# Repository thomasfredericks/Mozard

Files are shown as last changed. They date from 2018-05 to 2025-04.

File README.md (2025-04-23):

# Mozard

Mozard is a miniature, open-source digital synthesizer based on the Mozzi audio library and an Arduino Nano (ATmega328p) board.

[Video demonstration](https://youtu.be/wlpf26ogcaQ)

Features :

- 12 capacitive touch pads (one full octave)
- 6 different sound algorithms
- MIDI input support
- Octave control via potentiometer
- Volume control via potentiometer
- Built-in arpeggiator
- Decay and arpeggiator speed control

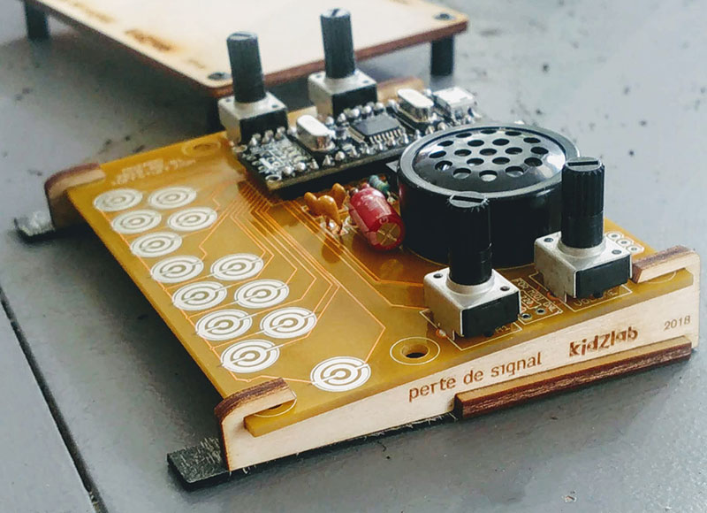
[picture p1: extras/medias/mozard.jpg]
A picture of the Mozard Mozard Kidzlab Synth


## Usage

The Mozard changes behavior when the arpeggiator is deactivated or activated. When in arpeggiator mode, the LED on the Arduino blinks in sync with the arpeggiator interval.

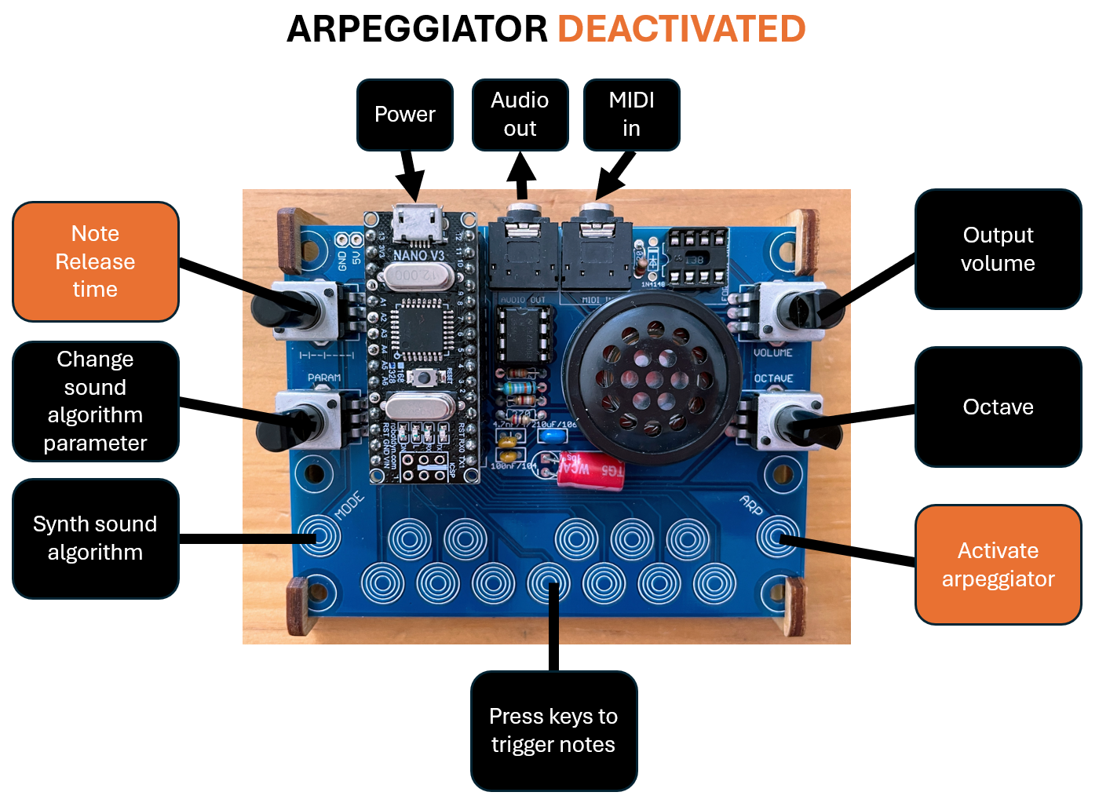
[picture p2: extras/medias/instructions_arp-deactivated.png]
How to use the Mozard when the arpeggiator is deactivated


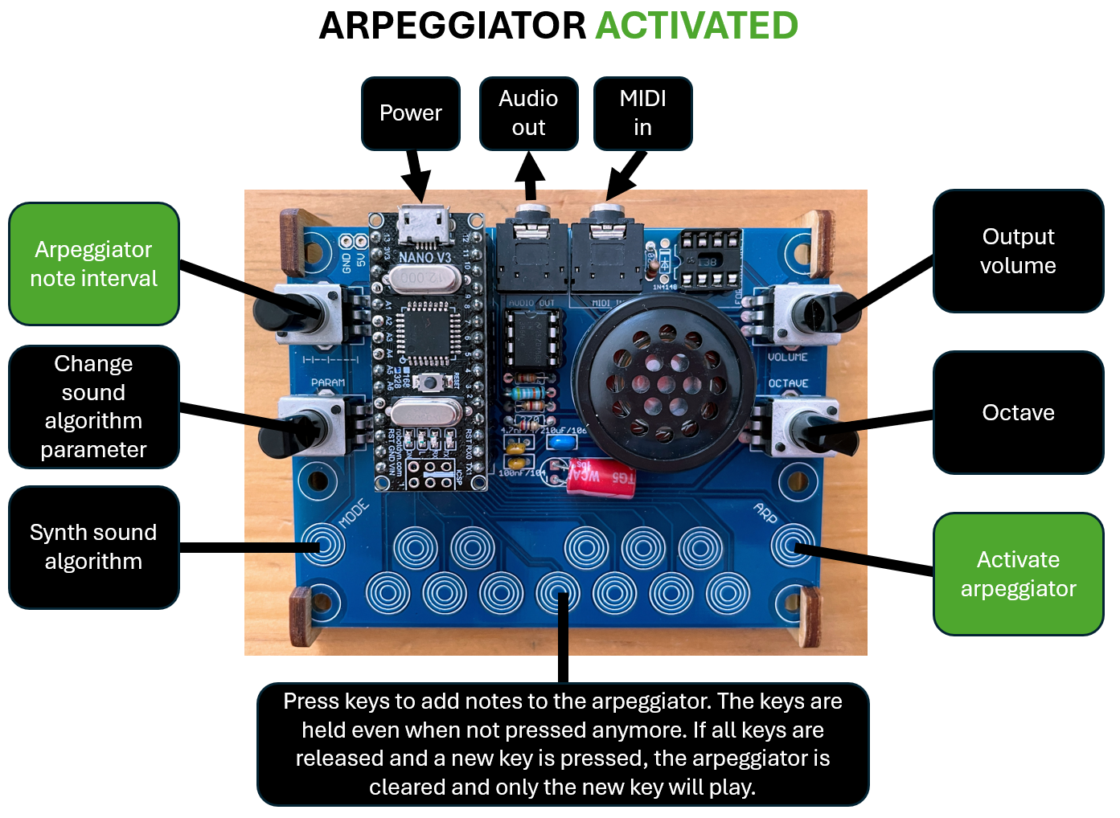
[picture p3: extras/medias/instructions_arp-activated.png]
How to use the Mozard when the arpeggiator is activated


## Hardware

The circuit and Bill Of Materials can be found in the extras/circuit folder.

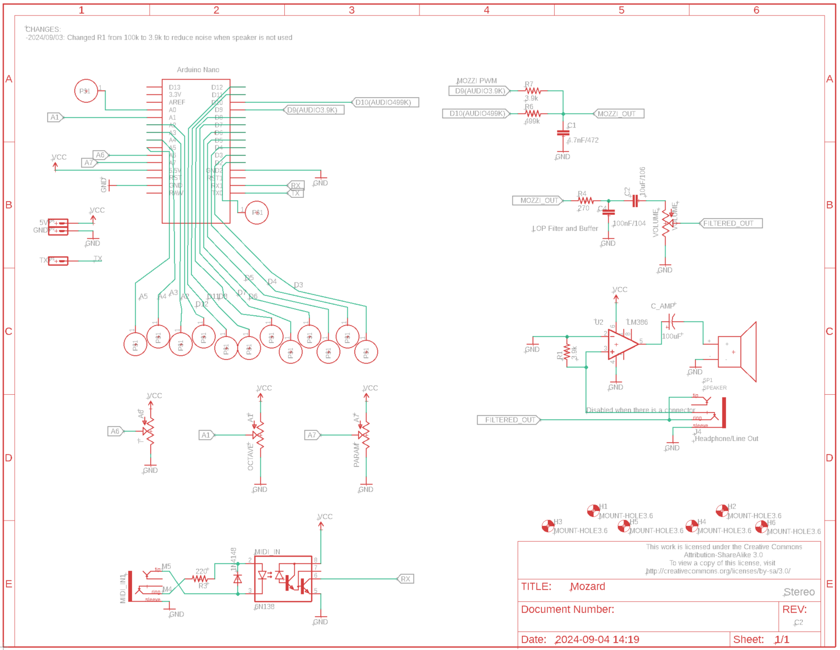
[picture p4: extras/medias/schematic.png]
A picture of Mozard schematic


## Source code

1) Download the library source code [here](https://github.com/thomasfredericks/Mozard/archive/refs/heads/master.zip).

2) Extract into your Arduino libraries folder. It should look something like this:
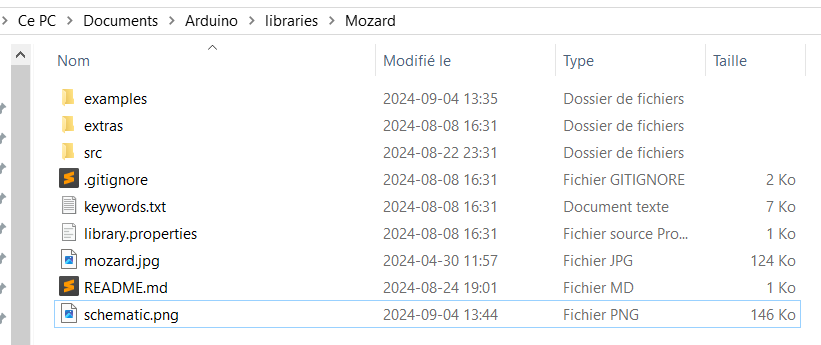
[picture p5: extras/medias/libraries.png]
The installed Mozard library in the Arduino libraries folder


3) Open Arduino.

4) Find the latest example:
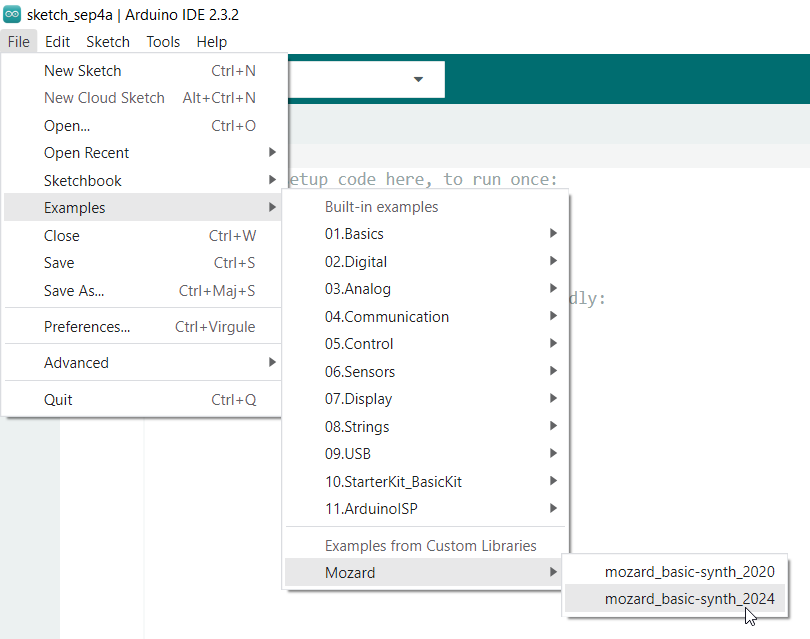
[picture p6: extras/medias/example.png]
Finding the latest example


5) Configure Arduino for the right microcontroller i.e. "Arduino Nano":
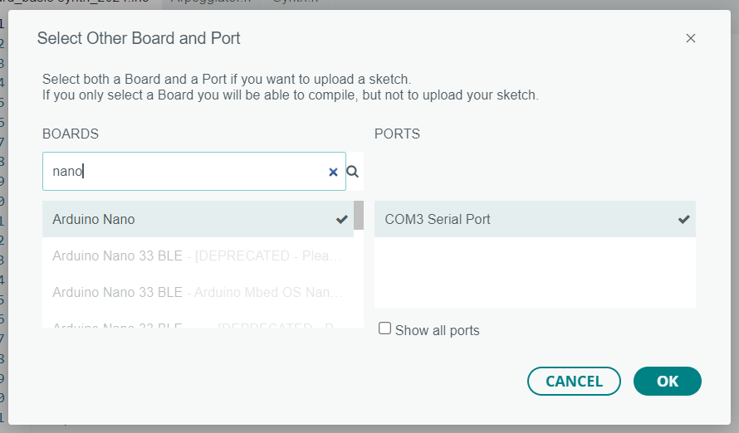
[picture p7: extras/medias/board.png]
Selecting Arduino Nano Board


7) Configure Arduino for the right Bootloader i.e. "ATmega328 (Old Bootloader)"  if you followed a Mozard workshop or bought a clone:
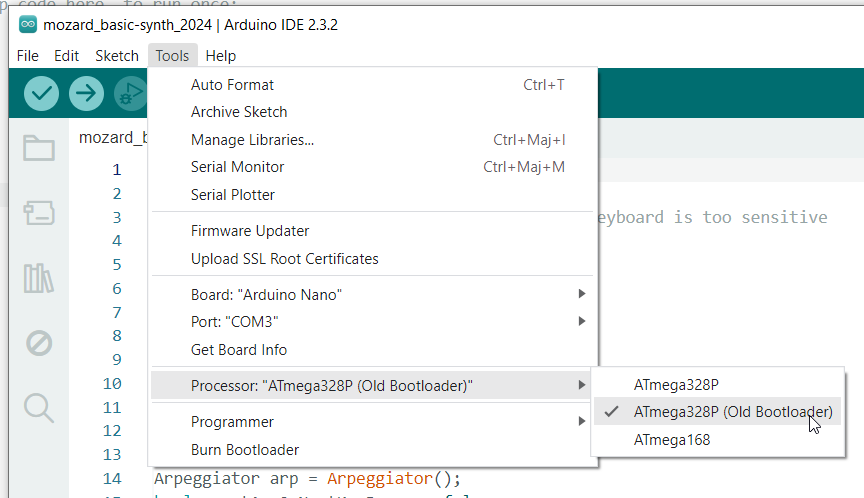
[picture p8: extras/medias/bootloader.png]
Selecting ATmega328 (Old Bootloader)


8) Compile and transfer.

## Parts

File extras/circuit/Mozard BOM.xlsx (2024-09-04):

Module | Quantity | Part | Digikey | Aliexpress
CORE | 1 | PCB
CORE | 1 | 4.7nF/472 CAPACITOR | ‎K472K15X7RF5TL2‎
CORE | 1 | 10uF/106 CAPACITOR | FK16X7R1C106K‎ or FK16X7R1C106M
CORE | 1 | 100nF/104 CAPACITOR | ‎K104K10X7RF53L2‎
CORE | 4 | ALPS POTENTIOMETER | ‎PTV09A-4020F-B503‎ | https://tinyurl.com/yywexyto (50k model) (https://tinyurl.com/yywexyto%20(50k%20model))
CORE | 1 | 270 RESISTOR | CFM14JT270R
CORE | 1 | 499k RESISTOR | RNF14FTD499K‎
CORE | 1 | 3.9k RESISTOR | CFM14JT3K90‎
CORE | 1 | AUDIO-JACK | SJ1-3525N | http://tinyurl.com/y95h5cap
CORE | 2 | FEMALE HEADERS | PPTC151LFBN-RC | https://tinyurl.com/y6tcve45
CORE | 1 | ARDUINO NANO 328 |  | https://tinyurl.com/y2zfy82b
SPEAKER | 1 | 3.9k RESISTOR | CFM14JT3K90‎
SPEAKER | 1 | LM386 | LM386N-4/NOPB‎ | http://tinyurl.com/yd4p9tap
SPEAKER | 1 | SPEAKER | 668-1136-ND | https://tinyurl.com/yxnvhumu
MIDI IN | 1 | AUDIO-JACK | CP1-3525N-ND | http://tinyurl.com/y95h5cap
MIDI IN | 1 | 6N138 | 160-1795-ND (https://www.digikey.ca/product-detail/en/lite-on-inc/6N138/160-1795-ND/1969179) | https://tinyurl.com/y5rocrjj
MIDI IN | 1 | 1N4148 | 1N4148FS-ND (https://www.digikey.ca/product-detail/en/on-semiconductor/1N4148/1N4148FS-ND/458603) | https://tinyurl.com/y25v8b57
MIDI IN | 1 | 220 RESISTOR | CFM14JT220R (https://www.digikey.ca/product-detail/en/stackpole-electronics-inc/CFM14JT220R/S220QCT-ND/2617711)

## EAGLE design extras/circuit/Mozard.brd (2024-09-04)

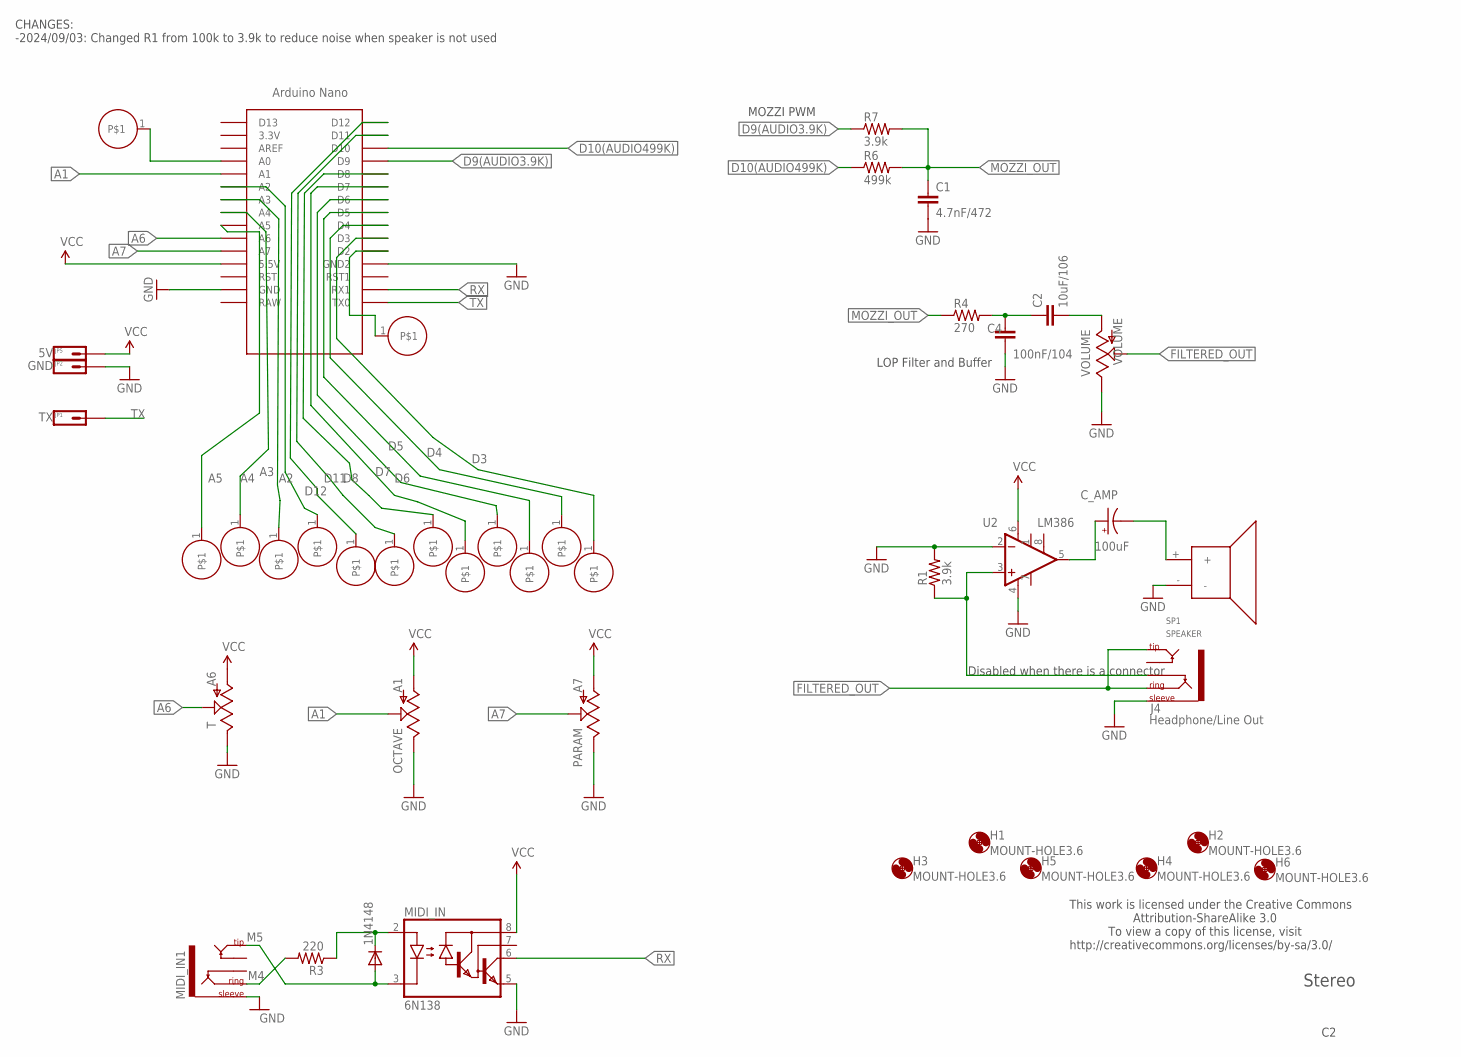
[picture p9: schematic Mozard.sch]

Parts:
1N4148: 1N4148; DO41-10
C1: 4.7nF/472; CAP-PTH-SMALL-KIT
C2: 10uF/106; CAP-PTH-SMALL-KIT
C4: 100nF/104; CAP-PTH-SMALL-KIT
C_AMP: 100uF; CPOL-RADIAL-10UF-25V
H1, H2, H3, H4, H5, H6: MOUNT-HOLE3.6; 3,6
J4: Headphone/Line Out; AUDIO-JACK
JP1: TX; 1X01_SIDE_NAME
JP2: GND; 1X01_SIDE_NAME
JP5: 5V; 1X01_SIDE_NAME
MIDI_IN: 6N138; DIL08
MIDI_IN1: AUDIO-JACKKIT; AUDIO-JACK-KIT
OCTAVE: A1; ALPS_POT
PARAM: A7; ALPS_POT
R1, R7: 3.9k; 0204/7
R3: 220; 0204/5
R4: 270; 0204/7
R6: 499k; 0204/7
SP1: SPEAKER; PCB_MOUNT_SPEAKER
T: A6; ALPS_POT
U2: LM386; DIP08
U$1: NANO
U$2, U$3, U$4, U$5, U$6, U$7, U$8, U$9, U$10, U$11, U$12, U$13, U$14, U$15: PCB-TOUCHPAD-1-PIN
VOLUME: VOLUME; ALPS_POT

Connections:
A1: OCTAVE.P$2 (S), U$1.A1
A2: U$1.A2, U$5.1
A3: U$1.A3, U$4.1
A4: U$1.A4, U$3.1
A5: U$1.A5, U$2.1
A6: T.P$2 (S), U$1.A6
A7: PARAM.P$2 (S), U$1.A7
D3: U$1.D3, U$13.1
D4: U$1.D4, U$12.1
D5: U$1.D5, U$11.1
D6: U$1.D6, U$10.1
D7: U$1.D7, U$9.1
D8: U$1.D8, U$8.1
D9(AUDIO3.9K): R7.1, U$1.D9
D10(AUDIO499K): R6.1, U$1.D10
D11: U$1.D11, U$7.1
D12: U$1.D12, U$6.1
FILTERED_OUT: J4.RING, J4.TIP, VOLUME.P$2 (S)
GND: C1.2, C4.2, J4.SLEEVE, JP2.1, MIDI_IN.5 (GND), MIDI_IN1.SLEEVE, OCTAVE.P$1 (E), PARAM.P$1 (E), R1.2, SP1.-, T.P$1 (E), U2.2 (-IN), U2.4 (V-), U$1.GND, U$1.GND1 (GND2), VOLUME.P$1 (E)
M4: MIDI_IN1.RING, R3.2
M5: 1N4148.A, MIDI_IN.3 (C), MIDI_IN1.TIP
MOZZI_OUT: C1.1, R4.1, R6.2, R7.2
unnamed: C_AMP.+, U2.5 (OUT)
unnamed: C2.2, VOLUME.P$3 (A)
unnamed: U$1.A0, U$15.1
unnamed: C2.1, C4.1, R4.2
unnamed: C_AMP.-, SP1.+
unnamed: J4.RSH, R1.1, U2.3 (+IN)
unnamed: 1N4148.C, MIDI_IN.2 (A), R3.1
RX: MIDI_IN.6 (VO), U$1.RX1
TOUCH_A: U$1.D2, U$14.1
TX: JP1.1, U$1.TX0
VCC: JP5.1, MIDI_IN.8 (VCC), OCTAVE.P$3 (A), PARAM.P$3 (A), T.P$3 (A), U2.6 (V+), U$1.5V (5.5V)

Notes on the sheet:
Stereo
Disabled when there is a connector
This work is licensed under the Creative Commons Attribution-ShareAlike 3.0 To view a copy of this license, visit http://creativecommons.org/licenses/by-sa/3.0/
LOP Filter and Buffer
MOZZI PWM
CHANGES: -2024/09/03: Changed R1 from 100k to 3.9k to reduce noise when speaker is not used

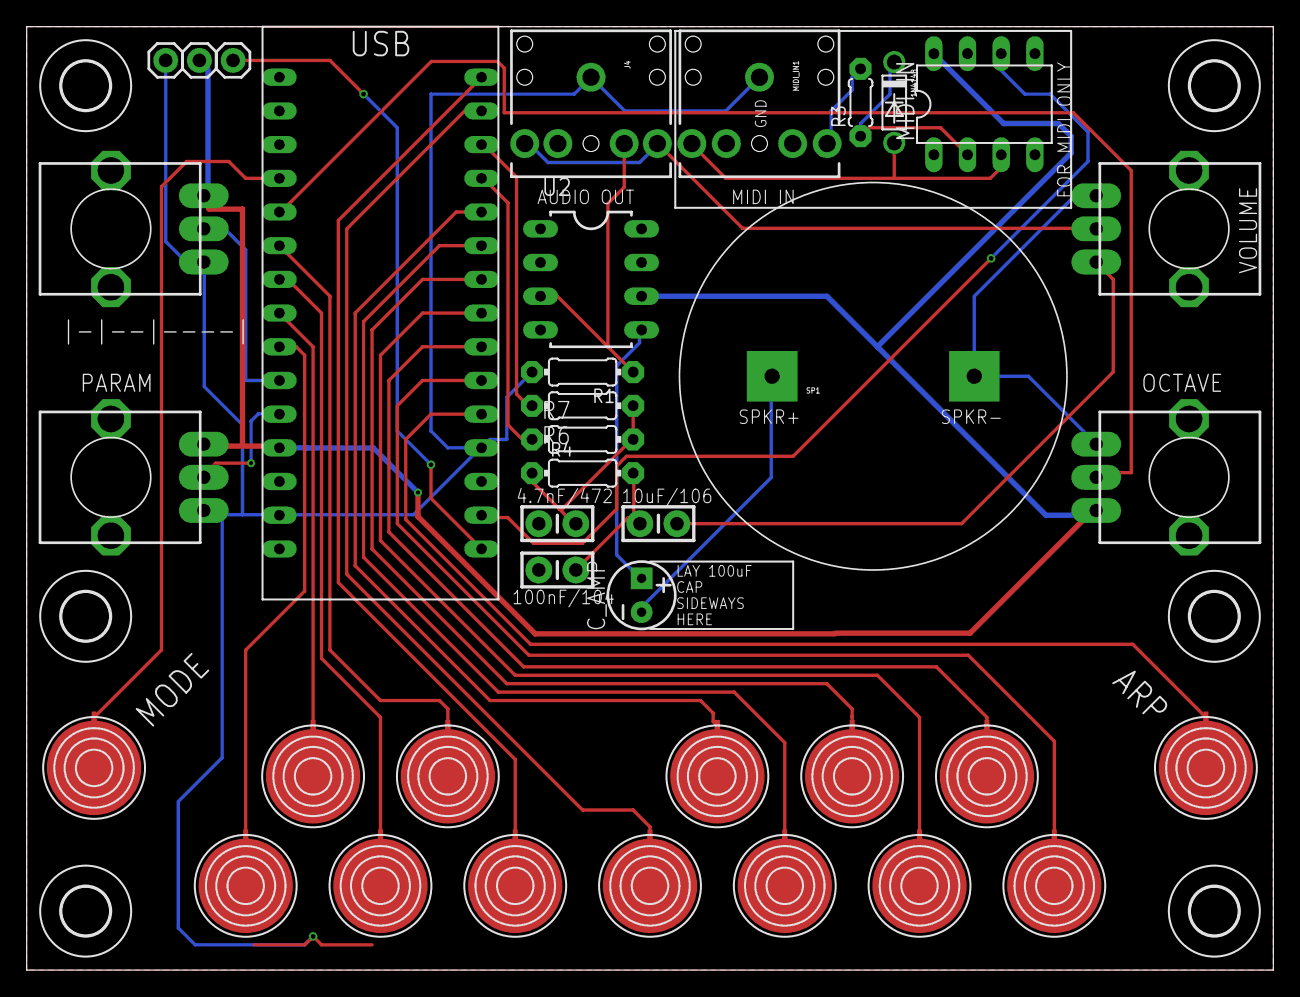
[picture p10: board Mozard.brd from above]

Board: 2 copper layers, 94.0 x 71.1 mm, 43 parts (0 on the bottom side), 33 nets.

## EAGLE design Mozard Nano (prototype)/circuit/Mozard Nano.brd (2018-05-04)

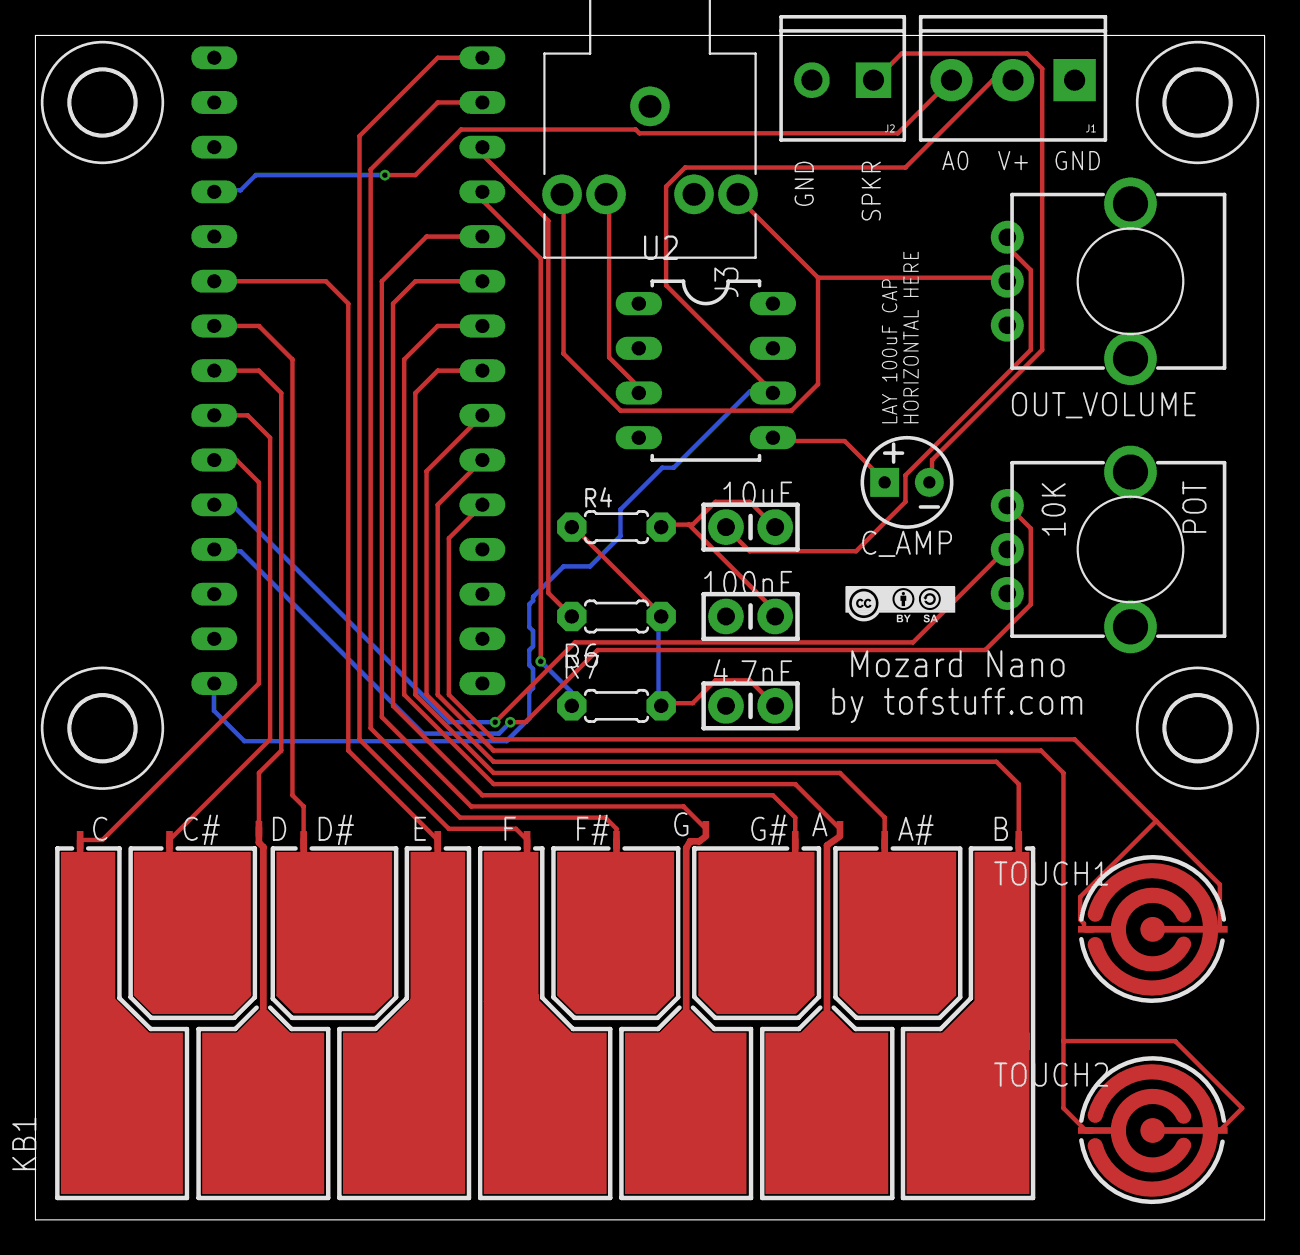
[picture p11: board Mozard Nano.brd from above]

Board: 2 copper layers, 69.8 x 67.3 mm, 22 parts (0 on the bottom side), 28 nets.

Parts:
C1: 4.7nF; CAP-PTH-SMALL-KIT
C2: 10uF; CAP-PTH-SMALL-KIT
C4: 100nF; CAP-PTH-SMALL-KIT
C_AMP: 100uF; CPOL-RADIAL-10UF-25V
H1, H2, H3, H4: MOUNT-HOLE3.6; 3,6
J1: SCREWTERMINAL-3.5MM-3
J2: SPKR; SCREWTERMINAL-3.5MM-2
J3: OUT; STEREO-AUDIO-3.5MM-SWITCHED
KB1: PCB-KEYBOARD4
OUT_VOLUME: 10K; ALPS_POT_KIT
POT: 10K; ALPS_POT_KIT
R4: 270; 0204/5
R6: 499k; 0204/5
R7: 3.9k; 0204/5
TOUCH1, TOUCH2: PCB-TOUCHPAD2
U2: LM386; DIP08
U$1: NANO
U$2: CC-BY-SA-LOGO2

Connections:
A0: J1.3, U$1.A0
D2(C): KB1.D#, U$1.A3
D9(AUDIO3.9K): R7.1, U$1.D9
D10(AUDIO499K): R6.1, U$1.D10
GND: C1.2, C4.2, J1.1, J2.2, J3.1, OUT_VOLUME.P$3, POT.P$3, U2.2, U2.4, U$1.GND, U$1.GND1
unnamed: C_AMP.-, J2.1
unnamed: KB1.E, U$1.A2
unnamed: KB1.C, U$1.A6
unnamed: C2.1, C4.1, R4.2
unnamed: C2.2, OUT_VOLUME.P$1
unnamed: J3.4, U2.3
unnamed: C_AMP.+, U2.5
unnamed: J3.2, J3.5, OUT_VOLUME.P$2
unnamed: KB1.C#, U$1.A5
unnamed: KB1.D, U$1.A4
unnamed: KB1.F, U$1.D12
unnamed: KB1.F#, U$1.D11
unnamed: KB1.G, U$1.D8
unnamed: KB1.G#, U$1.D7
unnamed: KB1.A, U$1.D6
unnamed: KB1.A#, U$1.D5
unnamed: KB1.B, U$1.D4
POT: POT.P$2, U$1.A7
TOUCH_A: TOUCH1.1, TOUCH1.2, U$1.D2
TOUCH_B: TOUCH2.1, TOUCH2.2, U$1.D3
UNFILTERED_OUT: C1.1, R4.1, R6.2, R7.2
V+: J1.2, U2.6, U$1.RAW
VCC: POT.P$1, U$1.5V

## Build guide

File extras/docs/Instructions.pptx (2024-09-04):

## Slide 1

ARPEGGIATOR DEACTIVATED

Power

Audio out

MIDI
in

Note Release time

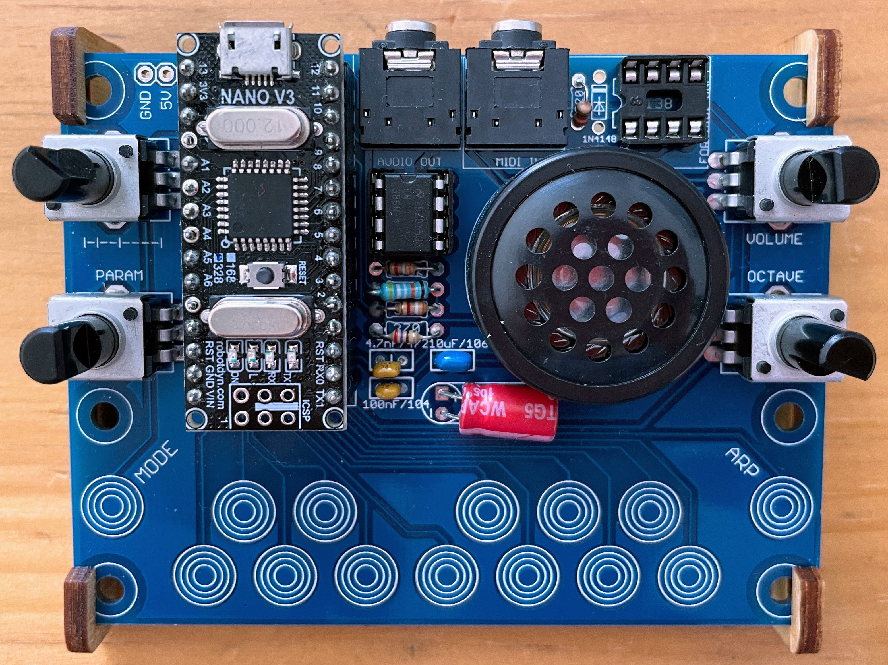
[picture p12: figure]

Output volume

Change sound algorithm parameter

Octave

Synth sound algorithm

Activate arpeggiator

Press keys to trigger notes

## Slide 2

ARPEGGIATOR ACTIVATED

Power

Audio out

MIDI
in

Arpeggiator note interval

Press keys to add notes to the arpeggiator. The keys are held even when not pressed anymore. If all keys are released and a new key is pressed, the arpeggiator is cleared and only the new key will play.

Output volume

Change sound algorithm parameter

Octave

Synth sound algorithm

Activate arpeggiator

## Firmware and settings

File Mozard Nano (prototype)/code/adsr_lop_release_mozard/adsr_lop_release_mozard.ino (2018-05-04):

/*
    IMPORTANT: this sketch requires Mozzi/mozzi_config.h to be
    be changed from STANDARD mode to HIFI.
    In Mozz/mozzi_config.h, change
    #define AUDIO_MODE STANDARD
    //#define AUDIO_MODE HIFI
    to
    //#define AUDIO_MODE STANDARD
    #define AUDIO_MODE HIFI

*/


#include <MozziGuts.h>
#include <Oscil.h>
#include <Ead.h> // Exponential attack decay envelope.
#include <mozzi_rand.h>
#include <mozzi_midi.h>
#include <LowPassFilter.h>
#include <ADSR.h>

// powers of 2 please : fast control rate for fast key response
#define CONTROL_RATE 256

//Oscillator Tables used for output Waveshape
// SELECT ONE PAIR :
//#include <tables/sin2048_int8.h>
//Oscil <2048, AUDIO_RATE> osc(SIN2048_DATA);

//#include <tables/triangle2048_int8.h>
//Oscil <2048, AUDIO_RATE> osc(TRIANGLE2048_DATA);

//#include <tables/saw2048_int8.h>
//Oscil <2048, AUDIO_RATE> osc(SAW2048_DATA);

#include <tables/square_no_alias_2048_int8.h>
Oscil <2048, AUDIO_RATE> osc(SQUARE_NO_ALIAS_2048_DATA);

// LFO TABLE
#include <tables/cos2048_int8.h> // for filter modulation
Oscil<COS2048_NUM_CELLS, CONTROL_RATE> lfo(COS2048_DATA);


ADSR <CONTROL_RATE, AUDIO_RATE> envelope;

LowPassFilter lpf;

uint8_t lastNote;

#include "MozardNano.h"

void setup() {

  Serial.begin(57600);
  startMozzi(CONTROL_RATE);


  // HARDWARE SETUP
  mozard.setup();

  lpf.setResonance(10);

  envelope.setADLevels(250,250);               // Sets Attack and Decay Levels; assumes Sustain, Decay, and Idle times
  envelope.setDecayTime(100);                  // Sets Decay time in milliseconds
  envelope.setSustainTime(32500);              // Sustain Time setting for envelope
  envelope.setReleaseTime(250); 

}


void updateControl() {

  mozard.updateControl();

  if ( mozard.buttonUpPressed() ) mozard.octaveUp();
  if ( mozard.buttonDownPressed() ) mozard.octaveDown();

  if ( mozard.keyPressed() ) {
    lastNote = mozard.getNotePressed();
    int freq = mtof(lastNote);
    
    osc.setFreq(freq);

    envelope.noteOn();

  }

  if ( mozard.keyReleased() ) {
    if ( lastNote == mozard.getNoteReleased() ) envelope.noteOff();
     
  }

 
  envelope.update();
  
   int pot = mozard.getPot0();
  
   lfo.setFreq( (float)pot * 0.05f);
   byte cutoff_freq = lfo.next() / 4 + 32;
   lpf.setCutoffFreq(cutoff_freq);


}


int updateAudio() {

 return (int) (lpf.next(osc.next()) * envelope.next())>>2;
}


void loop() {
  audioHook();
}

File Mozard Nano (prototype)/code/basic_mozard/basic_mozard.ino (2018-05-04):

/*
    IMPORTANT: this sketch requires Mozzi/mozzi_config.h to be
    be changed from STANDARD mode to HIFI.
    In Mozz/mozzi_config.h, change
    #define AUDIO_MODE STANDARD
    //#define AUDIO_MODE HIFI
    to
    //#define AUDIO_MODE STANDARD
    #define AUDIO_MODE HIFI

*/


#include <MozziGuts.h>
#include <Oscil.h>
#include <Ead.h> // Exponential attack decay envelope.
#include <mozzi_rand.h>
#include <mozzi_midi.h>
#include <tables/sin2048_int8.h> // sine table for oscillator

#include "MozardNano.h"

// powers of 2 please
#define CONTROL_RATE 256

Oscil <SIN2048_NUM_CELLS, AUDIO_RATE> aSin(SIN2048_DATA);
Ead envelope(CONTROL_RATE);
int gain;

unsigned int attack_ms = 10;
unsigned int decay_ms = 200;

void setup() {

  Serial.begin(57600);
  startMozzi(CONTROL_RATE);

  mozard.setup();

}


void updateControl() {

  mozard.updateControl();

  if ( mozard.buttonUpPressed() ) mozard.octaveUp();
  if ( mozard.buttonDownPressed() ) mozard.octaveDown(); 

  if ( mozard.keyPressed() ) {
    uint8_t note = mozard.getNotePressed();
    int freq = mtof(note);
    aSin.setFreq(freq);

    int pot = mozard.getPot0();
    envelope.start(attack_ms, pot * 2 + decay_ms);
    
  }

  gain = (int) envelope.next();

}


int updateAudio() {
  //return aSin.next() << 6; // 8 bits scaled up to 14 bits

  return (int) (gain * aSin.next()) >> 2; // 16 bits scaled to 14 bits
}


void loop() {
  audioHook();
}

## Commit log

2018-05-20 Fixes and added other potentiometer
    [Mozard Nano.brd, Mozard Nano.sch]
2018-05-22 Separating prototype from final version
    [Mozard Nano.GBL, Mozard Nano.GBO, Mozard Nano.GBP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]
2018-07-25 Mozard Nano Prototype Release
    [Mozard Nano.brd, Mozard Nano.sch, Mozard.brd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]
2018-07-25 Version 1.00
    [Mozard Nano.brd, Mozard Nano.sch, Mozard.brd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]
2018-07-25 New version with grounded touch pads
    [Mozard Grounded Touch Pads.brd, Mozard Grounded Touch Pads.sch]
2018-07-27 Adding examples
    [Mozard Grounded Touch Pads.brd, Mozard Grounded Touch Pads.sch]
2018-07-27 Version sub directory
    [Mozard.brd, Mozard.sch]
2018-09-12 integrated Mozzi
    [Mozard.brd, Mozard.sch]
2018-09-12 Added circuit
    [Mozard.brd, Mozard.sch]
2019-02-16 Fixed overlapping traces
    [Mozard.brd, Mozard.sch]
2019-07-31 Sensitivity change
    [Mozard.brd, Mozard.sch]
2019-08-29 Cap removed, resistor added
    Big capacitor removed because it was useless. 100k resistor added between + and - of amp to cancel noise when jack plugged in.
    [Mozard 2019-08-29.brd, Mozard 2019-08-29.sch, Mozard.sch]
2019-09-10 Removed a debug print
2019-09-10 Added MIDI
    [BOM.xlsx, Mozard 2019-08-29.brd, Mozard 2019-08-29.sch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]
2019-11-07 New board + poly
    [BOM.xlsx, Mozard BOM.xlsx, Mozard.brd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]
2020-12-08 New version
    [Mozard 2020-10-18.brd, Mozard 2020-10-18.sch, Mozard BOM.xlsx]
2022-01-25 Updated BOM
    [Mozard BOM.xlsx]

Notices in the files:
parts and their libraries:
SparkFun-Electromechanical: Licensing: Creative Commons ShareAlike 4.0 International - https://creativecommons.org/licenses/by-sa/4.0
